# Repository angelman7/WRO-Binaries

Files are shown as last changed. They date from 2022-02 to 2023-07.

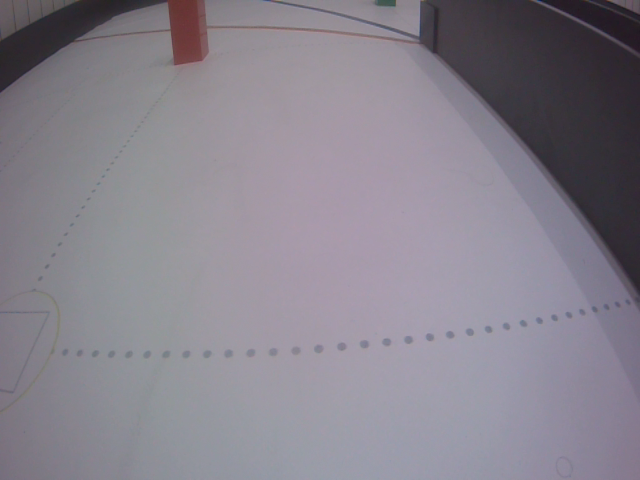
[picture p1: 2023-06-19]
jetson/scripts/images/img_12.png

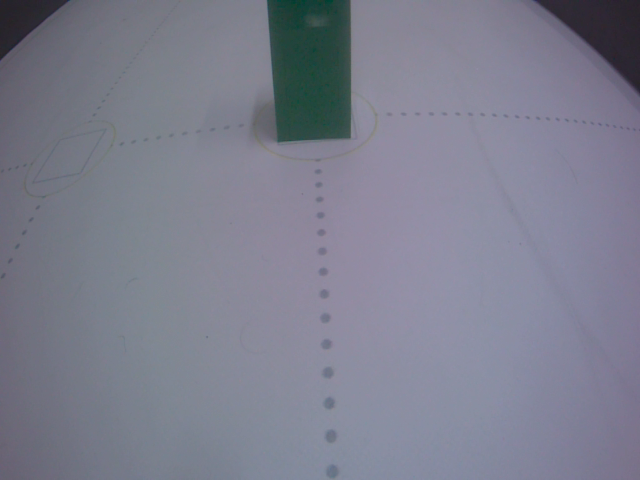
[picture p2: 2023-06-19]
jetson/scripts/images/img_3.png

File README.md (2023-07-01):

# WRO - Binaries

This repository contains engineering materials of a self-driven vehicle's model participating in the WRO Future Engineers competition in the season 2022 for the team Binaries.

## Content
* `t-photos` contains 2 photos of the team (an official one and one funny photo with all team members).
* `v-photos` contains 6 photos of the vehicle (from every side, from top and bottom).
* `video` contains the video.md file with the link to a video where driving demonstration exists.
* `schemes` contains one or several schematic diagrams in form of JPEG, PNG or PDF of the electromechanical components illustrating all the elements (electronic components and motors) used in the vehicle and how they connect to each other.
* `src` contains code of control software for all components which were programmed to participate in the competition.
* `models` is for the files for models used by 3D printers, laser cutting machines and CNC machines to produce the vehicle elements. If there is nothing to add to this location, the directory can be removed.
* `other` is for other files which can be used to understand how to prepare the vehicle for the competition. It may include documentation how to connect to a SBC/SBM and upload files there, datasets, hardware specifications, communication protocols descriptions etc. If there is nothing to add to this location, the directory can be removed.

## Introduction
First things first, the hardware consinsts of a Jetson Nano (running Linux) thats is the "mind" of the robot as it is where all the code is run.

Concerning the movement of the vehicle, a DC and a servo motor are used. The DC motor is responsible for the speed of the car while the servo motor is responsible for the steering of the car.

The Jetson Nano also utilises the power of R.O.S.(Robot Operating System) which is a set of software libraries and tools that let us build robot applications as this. From drivers to state-of-the-art algorithms, and with powerful developer tools.
Using R.O.S. all programs (besides the modules) can become a node and is able to publish and get information from other nodes through topics which is the perfect way for these programs to communicate.

The Jetson Nano also controls all the sensors used in our project:
* `1 color sensor` which detects the orange and blue line
* `2 laser distance sensors` that are used to determine the distance to the nearest wall from the fron oh the vehicle.
* `1 gyroscope / accelerometer` that is constantly use to determine and control the orientation of the vehicle.
* `1 camera` which is used to detect what is in front of the vehicle

On the software part the following programs and modules are used:
   - `pillar.py`
   - `run1.py` contains the main program that will run during the first part of the competition using the modules mentioned below.
   - `run2.py` contains the main program that will run during the second part of the competition using the modules mentioned below.
   - `modules`
       - `cnf.txt` contains many variables used by the car.py that were found through contious testing, like the color codes of the lines etc.
       - `bmm150.py`
       - `button.py` contains the class used to control the buttons that is used to detect whether or not a button is pressed.
       - `camera.py` contains the class used to read the camera.
       - `color.py` contains the class used for the color sensor and to check what it detects.
       - `compass.py` contains the class used to controll the compass and read the current orientation.
       - `cvtool.py` contains the class used to manage the camera and detect what and what type of obstacle is in front of the vehicle.
       - `drive.py` contains the class used for control and management of both the DC and servo.
       - `grove_i2c_bus.py` contains the bus used by the program grove_i2c_color_sensor_v2.py.
       - `grove_i2c_color_sesor_v2.py` contains the class used to control the I2C communication for both the OLED display and the Color Sensor.
       - `line2turn.py` contains the class used to detect and recognise the blue and orange lines on the field ground.
       - `oled.py` contains the class used to control the OLED display and showw text on it.
       - `oled_sample.py` a program used to debug the OLED display.
       - `wall.py` contains the class used by the camera to manage and detect and avoid any walls that might be in front of the vehicle correctly imminent.

**run1.py**
This program runs the program for the first challenge. It runs on a loop. Inside the loop, there is a hierarchy of activities that are performed for each frame of the camera. Firstly, the program checks, using the front distance sensors, whether or not the vehicle is dangerously close to a wall. Then, based on that information, a pid algorithm is used to calculate the steering angle of the vehicle. Then, the vehicle turns to avoid the wall. Alternatively, if no walls are detected it checks, through the distance sensor, whether or not the distance on the left or the right is over 2m, which signifies a left or right turn respectively. If any such distance is detected, left or right, the vehicle performes a 90 degree turn to move into the next section of the field. As the program uses an algorithm for the steering direction to stay parrallel to the walls, which is done using an angle target on the compass, a turn can be effectively executed by simply incrementing or dicrementing the target of the algorith by 90 degrees. After it has completed all the turns it stops in the starting sector. 

**run2.py** 
This program runs the program for the second challenge. It has multiple similarities to the run 1 function that runs in the first challenge. The only notable difference is that the program proceeds to check for pillars after the wall check. After the detection of a pillar, if it is present, the program will turn right or left, if needed, according to the distance, size and color (red or green) of the pillar. 

**pillar.py**
This file contains the program that has the finctionality of detecting the pillars and their position.

**cnf.txt**
The text file where values are stored after calibration, in order for them to be accessed and used by the run1 and run2 programs. 

**Modules Folder**
This is a folder that contains the modules that are used by the car.py program and by its numerous functions. 

# Credits - Libraries

- **Grove I2C Bus**

  **License**

  The MIT License (MIT)

  Grove Base Hat for the Raspberry Pi, used to connect grove sensors.
  Copyright (C) 2018  Seeed Technology Co.,Ltd. 

  Permission is hereby granted, free of charge, to any person obtaining a copy
  of this software and associated documentation files (the "Software"), to deal
  in the Software without restriction, including without limitation the rights
  to use, copy, modify, merge, publish, distribute, sublicense, and/or sell
  copies of the Software, and to permit persons to whom the Software is
  furnished to do so, subject to the following conditions:

  The above copyright notice and this permission notice shall be included in
  all copies or substantial portions of the Software.

  THE SOFTWARE IS PROVIDED "AS IS", WITHOUT WARRANTY OF ANY KIND, EXPRESS OR
  IMPLIED, INCLUDING BUT NOT LIMITED TO THE WARRANTIES OF MERCHANTABILITY,
  FITNESS FOR A PARTICULAR PURPOSE AND NONINFRINGEMENT. IN NO EVENT SHALL THE
  AUTHORS OR COPYRIGHT HOLDERS BE LIABLE FOR ANY CLAIM, DAMAGES OR OTHER
  LIABILITY, WHETHER IN AN ACTION OF CONTRACT, TORT OR OTHERWISE, ARISING FROM,
  OUT OF OR IN CONNECTION WITH THE SOFTWARE OR THE USE OR OTHER DEALINGS IN
  THE SOFTWARE.

 - **Grove I2C Color Sensor**
   
   Library for Grove - I2C Color Sensor V2(https://www.seeedstudio.com/Grove-I2C-Color-Sensor-V2-p-2890.html)

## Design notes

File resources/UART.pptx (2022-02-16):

## UART

Εφαρμογή με Jetson Nano & ESP32

## UART

- Το UART είναι η συντομογραφία του Universal Asynchronous Receiver/Transmitter.
- Είναι ένα κύκλωμα στους υπολογιστές το οποίο διαμεσολαβεί στην σειριακή επικοινωνία υπολογιστών ή υπολογιστών με συσκευές (ή και Embedded Computer Systems όπως μικροελεγκτές).
- Η ταχύτητα επικοινωνίας (ρυθμός μετάδοσης) μπορεί να παραμετροποιηθεί και μετριέται σε baud rate (bits/sec).
- Σήμερα το κύκλωμα UART είναι ενσωματωμένο ως κύκλωμα τσιπ μέσα στον υπολογιστή ή στην περιφερειακή συσκευή.

## UART

- Ένα UART παίρνει bytes δεδομένων και τα στέλνει σε σειριακή μορφή ως bits.
- Στον προορισμό ένα δεύτερο UART συλλέγει τα bits και δημιουργεί τα bytes δεδομένων που αποστάλθηκαν
- Η επικοινωνία μέσω του UART μπορεί να είναι απλή (simplex: προς μια κατεύθυνση μόνο - χωρίς να υπάρχει πρόβλεψη ο δέκτης να στείλει πίσω κάποιο σήμα), αμφίδρομη (πλήρης) ταυτόχρονη επικοινωνία (full duplex: και οι δύο συσκευές στέλνουν και δέχονται σήματα την ίδια στιγμή), αμφίδρομη εναλλασσόμενη επικοινωνία (half duplex: κάθε συσκευή παίρνει σειρά στο να αποστείλει ή να λάβει δεδομένα - δεν γίνεται αποστολή-λήψη την ίδια στιγμή)

## UART

- Κατά την επικοινωνία με UART στέλνονται πλαίσια δεδομένων (data frames) όπου το καθένα περιέχει ένα χαρακτήρα
- Το μέγεθος του πλαισίου χαρακτήρων μπορεί να είναι 10bits όπου υπάρχει ένα start bit και ένα stop bit στην αρχή και το τέλος και είναι διαθέσιμα 8 bits για την κωδικοποίηση του χαρακτήρα που στέλνουμε-παίρνουμε

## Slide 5

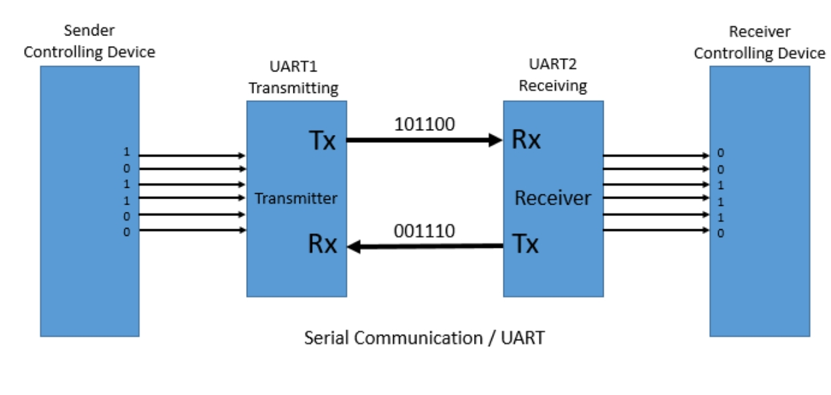
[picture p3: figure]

## Jetson Nano & ESP32

- Το Jetson Nano διαθέτει διάφορες θύρες UART, εμείς θα χρησιμοποιήσουμε τη θύρα που υποστηρίζεται από τα GPIOs D15 (RX) και D14 (TX), της οποία το όνομα είναι “/dev/ttyTHS1” (αυτό πρέπει αν το θυμόμαστε)
- Από την άλλη πλευρά θα έχουμε το ESP32, από το οποίο θα χρησιμοποιήσουμε τη θύρα που υποστηρίζεται από τα GIOPs 17 (ΤΧ2) και 16 (RX2), με όνομα τον αριθμό 2 (και αυτό πρέπει να το θυμόμαστε)
- Το TX του Jetson θα συνδεθεί με το RX του ESP32 και το RX του Jetson με το TX του ESP32

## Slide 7

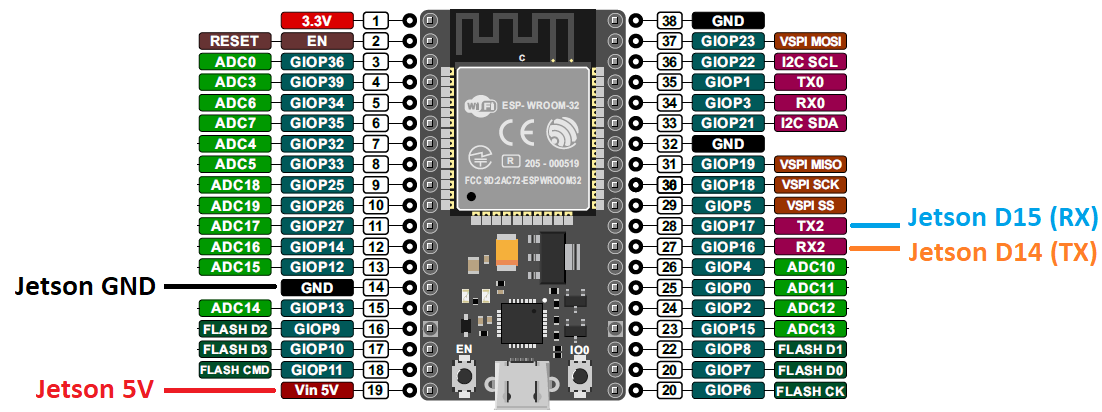
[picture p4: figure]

## MODULARITY

Jetson Nano
- Αξιοποίηση κάμερας ως αισθητήρα
- Ανίχνευση αντικειμένων ενδιαφέροντος
  - CV
  - Deep Learning
- Αποστολή δεδομένων στο UART

## MODULARITY

ESP32
- Διάβασμα αισθητήρων
  - Color, buttons, compass, gyroscope, accelerator …
- Λήψη δεδομένων από UART
- Επεξεργασία δεδομένων – μετρήσεων
  - PID controllers etc
- Έλεγχος actuators
  - DC Κινητήρας, steering κινητήρας, OLED, LEDs, buzzers …

## Jetson & ESP32

- Ο διαχωρισμός των λειτουργιών που θα υποστηρίζει ο κάθε ελεγκτής θα πρέπει να είναι σαφής και να μην επηρεάζεται η μεταξύ τους λειτουργία
- Απαραίτητος ο απομακρυσμένος έλεγχος του συστήματος:
  - Παρακολούθηση και διαχείριση του Jetson χωρίς την απευθείας σύνδεσή του με περιφερειακά (πληκτρολόγιο, οθόνη κλπ)
  - Παρακολούθηση των λήψεων της κάμερας για σκοπούς debugging
  - Δυνατότητα ελέγχου των κινητήρων και παρακολούθησης των αισθητήρων του ESP32 από τον χρήστη
  - Αυτοματοποίηση/τυποποίηση της διαδικασία “εκπαίδευσης”
    - Διαμόρφωση των thresholds στα επιθυμητά color spaces
    - Transfer learning σε DNN μοντέλα
    - …

## ESP32 – Micropython

from machine import UART
from time import time, sleep
from random import randrange
uart = UART(2, 115200)
kick = time()
while True:
if time() - kick > 1:
num = str(randrange(-10, 11))
uart.write(num.encode())
kick = time()
if uart.any():
message = uart.read().decode()
print(message)

## Jetson - Python

- https://github.com/JetsonHacksNano/UARTDemo

git clone https://github.com/JetsonHacksNano/UARTDemo
cd UARTDemo
sudo chmod 666 /dev/ttyTHS1
sudo python3 uart_example.py

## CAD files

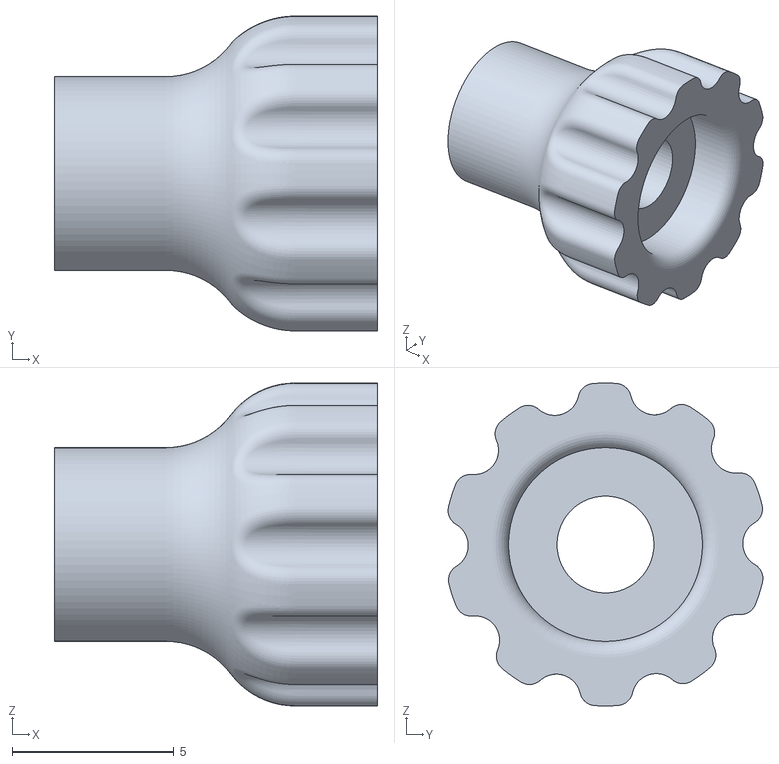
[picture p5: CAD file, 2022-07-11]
models/Camera_Rpi_Handle.stl
10.0 x 9.75 x 10.00

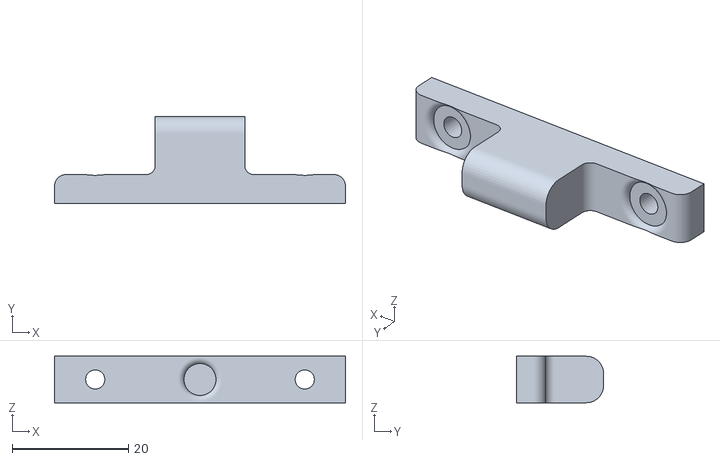
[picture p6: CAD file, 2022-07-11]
models/Camera_Rpi_Base.stl
50.0 x 15.0 x 8.00

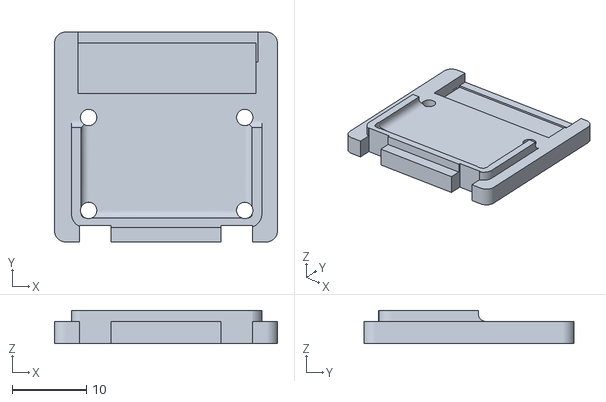
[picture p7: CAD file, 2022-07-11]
models/Camera_Rpi_Back.stl
30.0 x 28.2 x 4.50

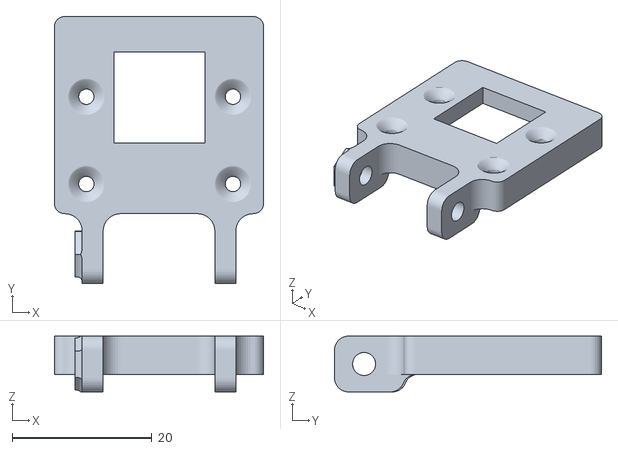
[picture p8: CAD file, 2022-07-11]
models/Camera_Rpi_Front.stl
30.0 x 38.2 x 8.00

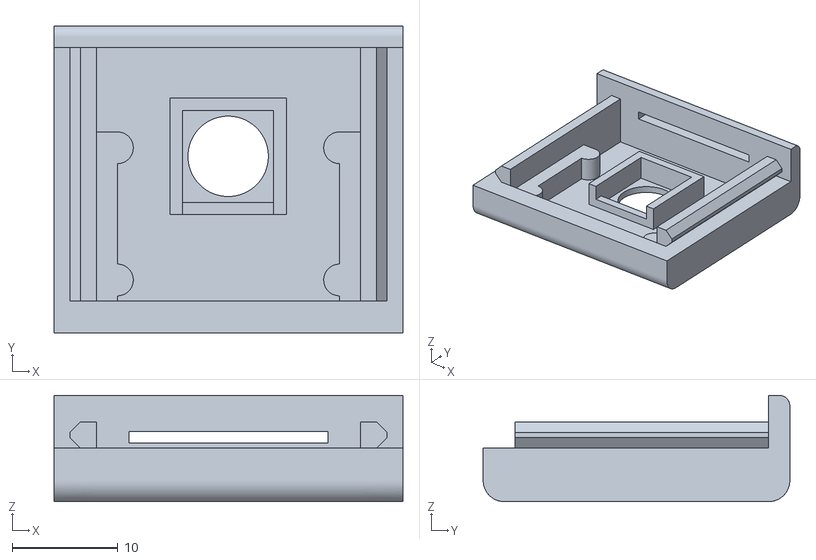
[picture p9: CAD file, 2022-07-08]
models/Cam-Housing-Front.stl
33.0 x 29.0 x 10.1

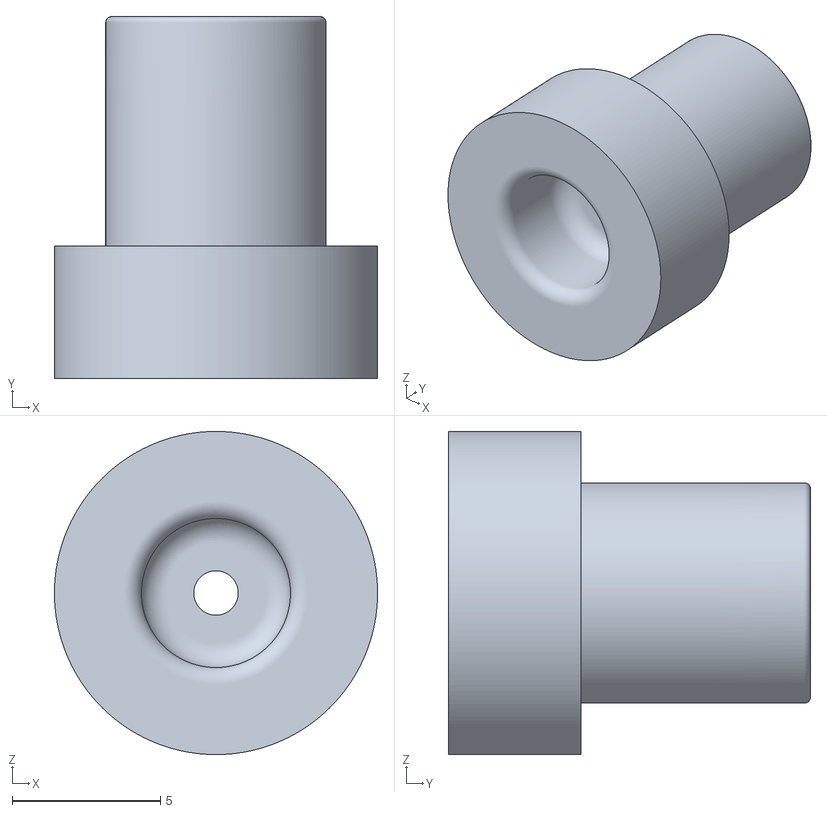
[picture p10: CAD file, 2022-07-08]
models/Servo-Connector.stl
10.9 x 12.2 x 10.9

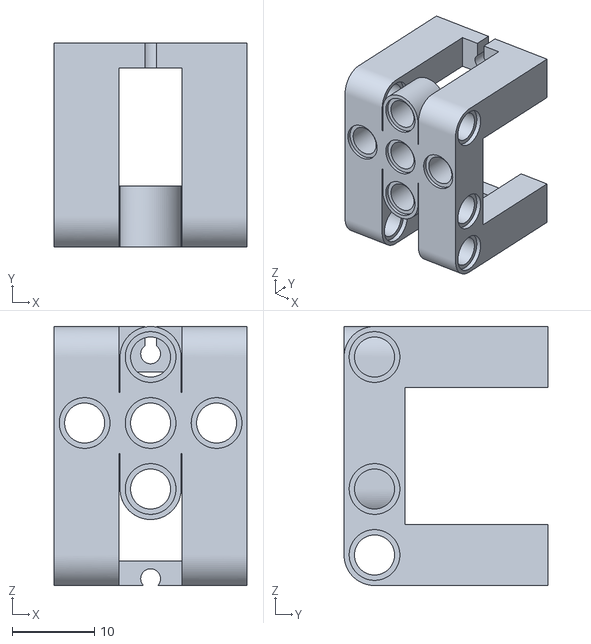
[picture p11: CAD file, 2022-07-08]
models/Servo-Bottom-holder.stl
23.4 x 24.7 x 31.4

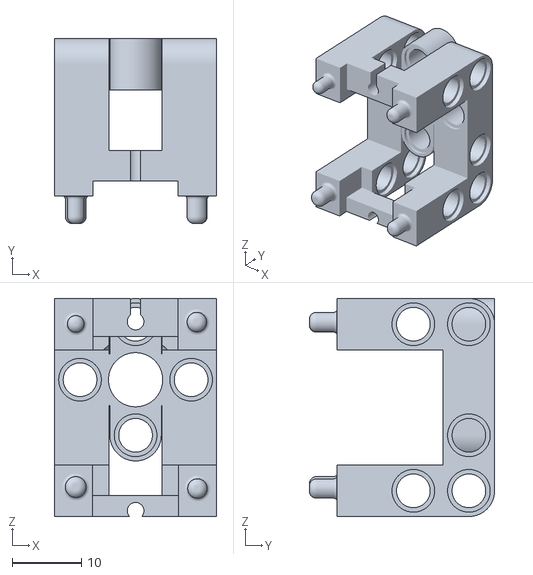
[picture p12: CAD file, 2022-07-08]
models/Servo-Top-holder.stl
23.4 x 26.7 x 31.4

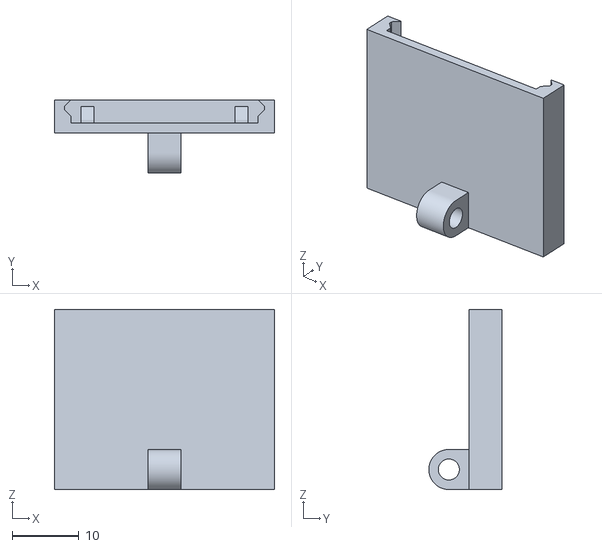
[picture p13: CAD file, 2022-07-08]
models/Cam-Housing-Back.stl
33.0 x 11.0 x 27.0

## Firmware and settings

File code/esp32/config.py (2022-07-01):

'''
MAIN CONFIGURATION FILE
'''
from machine import I2C, Pin, ADC, PWM # to manage ESP32
import ssd1306 # to manage OLED display
from time import sleep, time # to manage time
from math import pi, atan2, floor 
from ustruct import pack # to write data in sensors' registers
from array import array # to read bytes from sensors' registers
from json import loads# to read files
from hcsr04 import HCSR04

# I2C Color Sensor registers and commands
_CMD_CS      = 0x80
_AUTO_CS     = 0x20

_ENABLE_CS   = 0x00
_ATIME_CS    = 0x01
_WTIME_CS    = 0x03
_AILT_CS     = 0x04
_AIHT_CS     = 0x06
_PERS_CS     = 0x0C
_CONFIG_CS   = 0x0D
_CONTROL_CS  = 0x0F
_ID_CS       = 0x12
_STATUS_CS   = 0x13
_CDATA_CS    = 0x14
_RDATA_CS    = 0x16
_GDATA_CS    = 0x18
_BDATA_CS    = 0x1A

_AIEN_CS       = 0x10
_WEN_CS        = 0x08
_AEN_CS        = 0x02
_PON_CS        = 0x01

_GAINS_CS  = (1, 4, 16, 60)

PIN_SCL = 22
PIN_SDA = 21
PIN_POT = 36
PIN_NEXT_BTN = 2
PIN_PREV_BTN = 5
PIN_HIT_BTN = 0
PIN_IN1 = 12
PIN_IN2 = 14
PIN_ENA = 27
PIN_SERVO = 26
PIN_TRIG_LEFT = 33
PIN_ECHO_LEFT = 32
PIN_TRIG_RIGHT = 19
PIN_ECHO_RIGHT = 18

def map(x, in_min, in_max, out_min, out_max):
    return int(out_min + x *(out_max - out_min)/(in_max - in_min))

class Distance:
    def __init__(self):
        self.left_sensor = HCSR04(trigger_pin=PIN_TRIG_LEFT, echo_pin=PIN_ECHO_LEFT)
        self.right_sensor = HCSR04(trigger_pin=PIN_TRIG_RIGHT, echo_pin=PIN_ECHO_RIGHT)

    def right(self):
        return self.right_sensor.distance_cm()

    def left(self):
        return self.left_sensor.distance_cm()
        
class Display:
    def __init__(self):
        i2c = I2C(1, scl=Pin(PIN_SCL), sda=Pin(PIN_SDA))
        oled_width = 128
        oled_height = 64
        self.oled = ssd1306.SSD1306_I2C(oled_width, oled_height, i2c)
        
    def show_text_list(self, text_list, selected=-1):
        
        self.oled.fill(0)
        for i, t in enumerate(text_list):
            if selected == i:
                self.oled.text('>' + t, 0, i * 10)
            else:
                self.oled.text(t, 0, i * 10)
        self.oled.show()
        
    def show_text(self, text):
        self.oled.fill(0)
        self.oled.text(text, 0, 0)
        self.oled.show()

    def show_big_text(self, big_text):
        line = ""
        lines = []
        for c in big_text:
            if len(line) < 16:
                line += c
            else:
                lines.append(line)
                line = ""
                line += c
        if line != "":
            lines.append(line)
        print(lines)
        self.show_text_list(lines)
        
class Buttons:
    def __init__(self):
        self.next_button = Pin(PIN_NEXT_BTN, Pin.IN, Pin.PULL_UP) # DOWN
        self.hit_button = Pin(PIN_HIT_BTN, Pin.IN, Pin.PULL_UP) # CENTER
        self.previous_button = Pin(PIN_PREV_BTN, Pin.IN, Pin.PULL_UP) # UP
        
    def next_is_pressed(self):
        return True if self.next_button.value() == 0 else False
    
    def hit_is_pressed(self):
        return True if self.hit_button.value() == 0 else False
    
    def previous_is_pressed(self):
        return True if self.previous_button.value() == 0 else False

    def any_is_pressed(self):
        return self.next_button.value() == 0 or self.hit_button.value() == 0 or self.previous_button.value() == 0
    
    def wait_next(self):
        while self.next_button.value() == 1:
            pass
            
    def wait_hit(self):
        while self.hit_button.value() == 1:
            pass
        
    def wait_previous(self):
        while self.previous_button.value() == 1:
            pass

    def wait_button(self, buttons=["HIT", "NEXT", "PREVIOUS"]):
        while True:
            if self.hit_is_pressed() and "HIT" in buttons:
                return "HIT"
            if self.next_is_pressed() and "NEXT" in buttons:
                return "NEXT"
            if self.previous_is_pressed() and "PREVIOUS" in buttons:
                return "PREVIOUS"
        
class Compass:
    __gain__ = {
        '0.88': (0 << 5, 0.73),
        '1.3':  (1 << 5, 0.92),
        '1.9':  (2 << 5, 1.22),
        '2.5':  (3 << 5, 1.52),
        '4.0':  (4 << 5, 2.27),
        '4.7':  (5 << 5, 2.56),
        '5.6':  (6 << 5, 3.03),
        '8.1':  (7 << 5, 4.35)
    }

    # Correction to be set after calibration
    xs=1
    ys=1
    xb=0
    yb=0

    def __init__(self, scl=22, sda=21, address=0x1e, gauss='1.9', declination=(4, 54), 
                    cnf_file="cnf.txt"):
        self.orientation = {'forward':0, "backward":0, "left":0, "right":0}
        self.correction_values = {"xs":1, "ys":1, "xb":0, "yb":0}
        self.i2c = i2c = I2C(1, scl=Pin(22), sda=Pin(21))
        self.address = address
        
        i2c.writeto_mem(self.address, 0x00, pack('B', 0b111000))

        reg_value, self.gain = self.__gain__[gauss]
        i2c.writeto_mem(self.address, 0x01, pack('B', reg_value))

        i2c.writeto_mem(self.address, 0x02, pack('B', 0x00))
        self.declination = (declination[0] + declination[1] / 60) * pi / 180

        self.data = array('B', [0] * 6)
        self.cnf_file = cnf_file

        self.read_cnf_file()
        self.current_orientation = "forward"

    def init_orientation(self):
        degrees = self.read_degrees()
        for ort in self.orientation:
            min_value = (359 + self.orientation[ort] - 10) % 360
            max_value = (self.orientation[ort] + 10) % 360
            if min_value > max_value:
                min_value, max_value = max_value, min_value
            if min_value < degrees < max_value:
                if ort == "right":
                    self.orientation["forward"], self.orientation["left"], self.orientation["back"], self.orientation["right"] = self.orientation["right"], self.orientation["back"], self.orientation["left"], self.orientation["forward"] 
                elif ort == "back":
                    self.orientation["forward"], self.orientation["left"], self.orientation["back"], self.orientation["right"] = self.orientation["back"], self.orientation["left"], self.orientation["forward"], self.orientation["right"] 
                elif ort == "left":
                    self.orientation["forward"], self.orientation["left"], self.orientation["back"], self.orientation["right"] = self.orientation["left"], self.orientation["forward"], self.orientation["right"], self.orientation["back"] 
            break

    def read(self):
        data = self.data
        gain = self.gain

        self.i2c.readfrom_mem_into(self.address, 0x03, data)
        
        x = (data[0] << 8) | data[1]
        z = (data[2] << 8) | data[3]
        y = (data[4] << 8) | data[5]

        x = x - (1 << 16) if x & (1 << 15) else x
        y = y - (1 << 16) if y & (1 << 15) else y
        z = z - (1 << 16) if z & (1 << 15) else z

        x = x * gain
        y = y * gain
        z = z * gain
        
        # Apply calibration corrections
        x = x * self.xs + self.xb
        y = y * self.ys + self.yb

        return x, y, z

    def heading(self, x, y):
        heading_rad = atan2(y, x)
        heading_rad += self.declination

        # Correct reverse heading.
        if heading_rad < 0:
            heading_rad += 2 * pi

        # Compensate for wrapping.
        elif heading_rad > 2 * pi:
            heading_rad -= 2 * pi

        # Convert from radians to degrees.
        heading = heading_rad * 180 / pi
        degrees = floor(heading)
        minutes = round((heading - degrees) * 60)
        return degrees, minutes

    def read_degrees(self):
        x, y, z = self.read()
        return self.heading(x, y)[0]

    def format_result(self, x, y, z):
        degrees, minutes = self.heading(x, y)
        return 'X: {:.4f}, Y: {:.4f}, Z: {:.4f}, Heading: {}° {} '.format(x, y, z, degrees, minutes)

    def read_cnf_file(self):
        self.orientation = {'forward':0, "backward":0, "left":0, "right":0}
        self.correction_values = {"xs":1, "ys":1, "xb":0, "yb":0}
        with open(self.cnf_file, 'a') as f:
            for line in f:
                #print(line)
                dict_line = loads(line)
                if dict_line["data"] == "compass":
                    self.orientation['forward'] = dict_line["forward"]
                    self.orientation['backward'] = dict_line["backward"]
                    self.orientation['left'] = dict_line["left"]
                    self.orientation['right'] = dict_line["right"]
                    self.correction_values['xs'] = dict_line["xs"]
                    self.correction_values['ys'] = dict_line["ys"]
                    self.correction_values['xb'] = dict_line["xb"]
                    self.correction_values['yb'] = dict_line["yb"]
                    break
                
    def write_cnf_file(self, orientation=None, corrections=None):
        replacement = ""
        # read file to change the values
        with open(self.cnf_file, 'r') as f:
            # using the for loop
            for line in f:
                dict_line = loads(line)
                if dict_line["data"] == "compass":
                    if orientation is not None:
                        dict_line["forward"] = orientation["forward"]
                        dict_line["backward"] = orientation["backward"]
                        dict_line["left"] = orientation["left"]
                        dict_line["right"] = orientation["right"]
                    if corrections is not None:
                        dict_line["xs"] = corrections['xs']
                        dict_line["ys"] = corrections['ys']
                        dict_line["xb"] = corrections['xb']
                        dict_line["yb"] = corrections['yb']
                replacement = replacement + str(dict_line) + "\n"
        sleep(0.1)
        # re-write the file with the new values
        with open(self.cnf_file, 'w') as f:
            f.write(replacement.replace("\'", "\""))

class ColorSensor:
    """Driver for Grove I2C Color Sensor (TCS34725)"""

    def __init__(self, address=0x29, scl=22, sda=21, cnf_file="cnf.txt"):
        self.hsv_lines = None
        self.cnf_file = cnf_file
        self.i2c = I2C(1, scl=Pin(scl), sda=Pin(sda))
        
        self.address = address

        self.awake = False

        self.set_integration_time(24)
        self.set_gain(4)

        # read configuration file to update color ranges of lines
        self.read_cnf_file()

    def detect_color(self):
        # self.hsv_lines = {'white_min':0, "white_max":0, 'orange_min':0, "orange_max":0, "blue_min":0, "blue_max":0}
        hsv_values = self.hsv()
        if self.hsv_lines["white_hmin"] <= hsv_values[0] <= self.hsv_lines["white_hmax"] and \
            self.hsv_lines["white_vmin"] <= hsv_values[2] <= self.hsv_lines["white_vmax"]:
                #self.hsv_lines["white_smin"] <= hsv_values[1] <= self.hsv_lines["white_smax"] and \
                
            return "white"
        if self.hsv_lines["orange_hmin"] <= hsv_values[0] <= self.hsv_lines["orange_hmax"] and \
            self.hsv_lines["orange_vmin"] <= hsv_values[2] <= self.hsv_lines["orange_vmax"]:
                #self.hsv_lines["orange_smin"] <= hsv_values[1] <= self.hsv_lines["orange_smax"] and \
            return "orange"
        if self.hsv_lines["blue_hmin"] <= hsv_values[0] <= self.hsv_lines["blue_hmax"] and \
            self.hsv_lines["blue_vmin"] <= hsv_values[2] <= self.hsv_lines["blue_vmax"]:
                #self.hsv_lines["blue_smin"] <= hsv_values[1] <= self.hsv_lines["blue_smax"] and \
                
            return "blue"
        return "uknown"
        
    def line_calibration_is_valid(self, new_hsv_lines):
        if new_hsv_lines == None:
            return False
        for i in range(0, 360):
            if i in range(new_hsv_lines['white_hmin'], new_hsv_lines['white_hmax'] + 1) and \
                i in range(new_hsv_lines['orange_hmin'], new_hsv_lines['orange_hmax'] + 1) and \
                    i in range(new_hsv_lines['blue_hmin'], new_hsv_lines['blue_hmax'] + 1):
                    return False
        return True

    def wakeup(self):
        enable = self._read_byte(_ENABLE_CS)
        self._write_byte(_ENABLE_CS, enable | _PON_CS | _AEN_CS)
        sleep(0.0024)

        self.awake = True

    def sleep(self):
        enable = self._read_byte(_ENABLE_CS)
        self._write_byte(_ENABLE_CS, enable & ~_PON_CS)

        self.awake = False

    def is_awake(self):
        return self._read_byte(_ENABLE_CS) & _PON_CS

    def set_wait_time(self, t):
        pass

    def id(self):
        return self._read_byte(_ID_CS)

    def integration_time(self):
        steps = 256 - self._read_byte(_ATIME_CS)
        return steps * 2.4

    def set_integration_time(self, t):
        """Set the integration time of the sensor"""
        if t < 2.4:
            t = 2.4
        elif t > 614.4:
            t = 614.4
        
        steps = int(t / 2.4)
        self._integration_time = steps * 2.4
        self._write_byte(_ATIME_CS, 256 - steps)

    def gain(self):
        """The gain control. Should be 1, 4, 16, or 60.
        """
        return _GAINS_CS[self._read_byte(_CONTROL_CS)]

    def set_gain(self, gain):
        if gain in _GAINS_CS:
            self._write_byte(_CONTROL_CS, _GAINS_CS.index(gain))

    def raw(self):
        """Read RGBC registers
        return 16 bits red, green, blue and clear data
        """

        if not self.awake:
            self.wakeup()

        while not self._valid():
            sleep(0.0024)

        data = tuple(self._read_word(reg) for reg in (_RDATA_CS, _GDATA_CS, _BDATA_CS, _CDATA_CS))
        return data

    def hsv(self):
        r, g, b, clear = self.raw()
        
        if clear:
            r = r / clear
            g = g / clear
            b = b / clear
        else:
            r, g, b = 0, 0, 0

        #r, g, b = r / 255, g / 255, b / 255
        maxc = max(r, g, b)
        minc = min(r, g, b)
        v = maxc
        if minc == maxc:
            return 0.0, 0.0, v
        s = (maxc-minc) / maxc
        rc = (maxc-r) / (maxc-minc)
        gc = (maxc-g) / (maxc-minc)
        bc = (maxc-b) / (maxc-minc)
        if r == maxc:
            h = bc-gc
        elif g == maxc:
            h = 2.0+rc-bc
        else:
            h = 4.0+gc-rc
        h = (h/6.0) % 1.0
        return min(359, int(h*359)), min(255, int(s*255)), min(255, int(v*255))
        
    def rgb(self):
        """Read the RGB color detected by the sensor.  Returns a 3-tuple of
        red, green, blue component values as bytes (0-255).
        """
        r, g, b, clear = self.raw()
        
        if clear:
            r = int(255 * r / clear)
            g = int(255 * g / clear)
            b = int(255 * b / clear)
        else:
            r, g, b = 0, 0, 0
        return r, g, b

    def _valid(self):
        """Check if RGBC is valid"""
        return self._read_byte(_STATUS_CS) & 0x01

    def _read_byte(self, address):
    
        command = _CMD_CS | address
        data = array('B', [0])
        self.i2c.readfrom_mem_into(self.address, command, data)
        return data[0]

    def _read_word(self, address):
        command = _CMD_CS | _AUTO_CS | address
        data = array('B', [0] * 2)
        self.i2c.readfrom_mem_into(self.address, command, data)#self.bus.read_word_data(self.address, command)
        
        return (data[0] << 8) | data[1]

    def _write_byte(self, address, data):
        command = _CMD_CS | address
        self.i2c.writeto_mem(self.address, command, pack('B', data)) # pack('B', 0b111000)
        #self.bus.write_byte_data(self.address, command, data)

    def _write_word(self, address, data):
        command = _CMD_CS | _AUTO_CS | address
        data = [(data >> 8) & 0xFF, data & 0xFF]
        self.i2c.writeto_mem(self.address, command, pack('B', data))
        #self.bus.write_i2c_block_data(self.address, command, data)

    def read_cnf_file(self):
        self.hsv_lines = {"white_hmin":0, "white_hmax":0, "white_smin":0, "white_smax":0, "white_vmin":0, 
                        "white_vmax":0, "orange_hmin":0, "orange_hmax":0, "orange_smin":0, "orange_smax":0, 
                        "orange_vmin":0, "orange_vmax":0, "blue_hmin":0, "blue_hmax":0, "blue_smin":0, 
                        "blue_smax":0, "blue_vmin":0, "blue_vmax":0}
        with open(self.cnf_file, 'a') as f:
            for line in f:
                #print(line)
                dict_line = loads(line)
                if dict_line["data"] == "hsv_lines":
                    self.hsv_lines['white_hmin'] = dict_line["white_hmin"]
                    self.hsv_lines['white_hmax'] = dict_line["white_hmax"]
                    self.hsv_lines['white_smin'] = dict_line["white_smin"]
                    self.hsv_lines['white_smax'] = dict_line["white_smax"]
                    self.hsv_lines['white_vmin'] = dict_line["white_vmin"]
                    self.hsv_lines['white_vmax'] = dict_line["white_vmax"]
                    self.hsv_lines['orange_hmin'] = dict_line["orange_hmin"]
                    self.hsv_lines['orange_hmax'] = dict_line["orange_hmax"]
                    self.hsv_lines['orange_smin'] = dict_line["orange_smin"]
                    self.hsv_lines['orange_smax'] = dict_line["orange_smax"]
                    self.hsv_lines['orange_vmin'] = dict_line["orange_vmin"]
                    self.hsv_lines['orange_vmax'] = dict_line["orange_vmax"]
                    self.hsv_lines['blue_hmin'] = dict_line["blue_hmin"]
                    self.hsv_lines['blue_hmax'] = dict_line["blue_hmax"]
                    self.hsv_lines['blue_smin'] = dict_line["blue_smin"]
                    self.hsv_lines['blue_smax'] = dict_line["blue_smax"]
                    self.hsv_lines['blue_vmin'] = dict_line["blue_vmin"]
                    self.hsv_lines['blue_vmax'] = dict_line["blue_vmax"]
                    break
                
    def write_cnf_file(self, hsv_lines):
        replacement = ""
        # read file to change the values
        with open(self.cnf_file, 'r') as f:
            # using the for loop
            for line in f:
                dict_line = loads(line)
                if dict_line["data"] == "hsv_lines":
                    dict_line["white_hmin"] = hsv_lines["white_hmin"]
                    dict_line["white_hmax"] = hsv_lines["white_hmax"]
                    dict_line["white_smin"] = hsv_lines["white_smin"]
                    dict_line["white_smax"] = hsv_lines["white_smax"]
                    dict_line["white_vmin"] = hsv_lines["white_vmin"]
                    dict_line["white_vmax"] = hsv_lines["white_vmax"]
                    
                    dict_line["orange_hmin"] = hsv_lines["orange_hmin"]
                    dict_line["orange_hmax"] = hsv_lines["orange_hmax"]
                    dict_line["orange_smin"] = hsv_lines["orange_smin"]
                    dict_line["orange_smax"] = hsv_lines["orange_smax"]
                    dict_line["orange_vmin"] = hsv_lines["orange_vmin"]
                    dict_line["orange_vmax"] = hsv_lines["orange_vmax"]
                    
                    dict_line["blue_hmin"] = hsv_lines["blue_hmin"]
                    dict_line["blue_hmax"] = hsv_lines["blue_hmax"]
                    dict_line["blue_smin"] = hsv_lines["blue_smin"]
                    dict_line["blue_smax"] = hsv_lines["blue_smax"]
                    dict_line["blue_vmin"] = hsv_lines["blue_vmin"]
                    dict_line["blue_vmax"] = hsv_lines["blue_vmax"]
                replacement = replacement + str(dict_line) + "\n"
        sleep(0.1)
        # re-write the file with the new values
        with open(self.cnf_file, 'w') as f:
            f.write(replacement.replace("\'", "\""))

class DC:
    def __init__(self):
        self.in1 = Pin(PIN_IN1, Pin.OUT)
        self.in1.value(0)
        self.in2 = Pin(PIN_IN2, Pin.OUT)
        self.in2.value(0)
        self.ena = PWM(Pin(PIN_ENA), freq=50, duty=0)
        self.pot = ADC(Pin(PIN_POT))
        self.pot.atten(ADC.ATTN_11DB)
        self.pot.width(ADC.WIDTH_10BIT)
        self.max_pwm = 1023
        self.forward = True

    def set_direction(self, forward=True):
        if forward:
            self.forward = True
            self.in1.value(0)
            self.in2.value(1)
        else:
            self.forward = False
            self.in1.value(1)
            self.in2.value(0)

    def stop(self):
        self.in1.value(0)
        self.in2.value(0)

    def update_max_speed(self):
        self.max_pwm = self.pot.read()

    def read_pot(self):
        return self.pot.read()

    def move(self, speed=50, forward=True):
        speed_duty = int((self.max_pwm * speed) / 100)
        self.ena.duty(speed_duty)
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

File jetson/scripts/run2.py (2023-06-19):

#!/usr/bin/env python3
import rospy, time
from std_msgs.msg import String, Int16, Int16MultiArray, Int32MultiArray, Int8
import steering
from modules.pid import PID
from modules.button import Button
import RPi.GPIO as GPIO

encoder = Int32MultiArray() # left_encoder, main_encoder, right_encoder
encoder.data = [0, 0, 0]
# pillar_array.data = ["color", "cx", "cy", "height", "center"]
pillar = Int16MultiArray()
pillar.data = [0, 0, 0, 0, 0]
left_distance = right_distance = 0
gyro_pos = 0
line = 0
state = 0
steer = steering.Steering()
reference_angle = 0
gyro_target = 0
pub = rospy.Publisher('speed', String, queue_size=10)


def change_state(channel):
    global state

    if state == 0:
        state = 1
        rospy.loginfo("State changed to 1")
    elif state == 1:
        state = -1
        rospy.loginfo("State changed to -1")
    

button = Button(pin=21, method_to_run=change_state)

def line_callback(data):
    global line

    # rospy.loginfo(rospy.get_caller_id() + "Line %s", data.data)
    line = data.data

def reset_gyro_angle():
    global reference_angle

    reference_angle = gyro_pos

def read_angle():
    return reference_angle - gyro_pos


def distance_callback(data):
    global left_distance, right_distance

    #rospy.loginfo(rospy.get_caller_id() + "Distances %s", data.data)
    left_distance = data.data[0]
    right_distance = data.data[1]
    # print("LD: ", left_distance)
    # print("RD: ", right_distance)


def gyro_callback(data):
    global gyro_pos

    #rospy.loginfo(rospy.get_caller_id() + "Gyro angle %s", str(data.data))
    gyro_pos = data.data


def encoders_callback(data):
    global encoder

    #rospy.loginfo(rospy.get_caller_id() + "Encoders %s", data.data)
    encoder = data
    # print("Encoder: ", encoder.data)

def pillar_callback(data):
    global pillar

    # rospy.loginfo(rospy.get_caller_id() + "Pillar %s", data.data)
    pillar = data
    # print("Pillar: ", pillar.data)

    
def dc_speed(speed=0):
    msg = str(speed)
    #rospy.loginfo(msg)
    pub.publish(msg)


def get_target(color, center, height, kc=1, kh=1, min_center=30):
        center = (100 + center)/2
        # print("Color:", color)
        # print("Center:", center)
        if color == 1 and center > min_center:
            t = kc * center + (kh * 100 * height)/300
            # print("t:", t)
            return min(max(-100, int(t)), 100)
        if color == -1 and center < 100 - min_center:
            t = kc * center + (kh * 100 * height)/300
            # print("t:", t)
            return -1 * min(max(-100, int(t)), 100)
        #     return -1 * min(max(-100, int(kc * (100 + center)/2 + (kh * 100 * height)/300)), 100)
        return None


def drive_gyro(speed=50, main_position=0, pid_ks=(1, 0, 0)):
    global line, current_path, previous_path, gyro_target

    # Initialise PID object
    pid = PID(pid_ks[0], pid_ks[1], pid_ks[2])
    pid.SetPoint = 0
    pid.setSampleTime(0.005)
    dc_speed(speed)
    print("RUNNING")
    
    turns = 0
    last_pillar_turn_ticks = 0
    pillar_ticks_delay = 600

    last_wall_turn_ticks = 0
    wall_ticks_delay = 350

    min_wall_distance = 80
    
    current_path = 0
    previous_path = -1
    turns = 0
    gyro_target = main_position
    direction = 0
    last_turn_ticks = 0
    turn_ticks = 9000
    while state == 1 and not rospy.is_shutdown() and turns < 666:
        # Check line to change gyro target
        error = read_angle() + gyro_target
        
        turn_left_distance = left_distance > 1000 and abs(error) < 20
        turn_right_distance = right_distance > 1000 and abs(error) < 20
        
        if turn_left_distance:
            direction = -1
        elif turn_right_distance:
            direction = 1
        if line != 0: # and ticks - last_line_turn_ticks > line_ticks_delay: #current_ms - last_line_turn_ms > line_delay:
            if encoder.data[1] - last_turn_ticks > turn_ticks:
                direction = line
            else:
                line = 0

        if encoder.data[1] - last_turn_ticks > turn_ticks and direction != 0:
            last_turn_ticks = encoder.data[1]
            gyro_target += -1*direction*90
            line = 0
            turns += 1
            rospy.loginfo("Turn " + str(turns) + ": " + str(direction) + ", ticks:" + str(encoder.data[1]))
        elif direction != 0:
            direction = 0
                    
        # 1st priority the wall
        if left_distance < min_wall_distance:
            rospy.loginfo("L-Wall fix")
            # rospy.loginfo("left wall " + str(left_distance))
            steer.set_steering(100)
            last_wall_turn_ticks = encoder.data[1]
            
        if right_distance < min_wall_distance:
            rospy.loginfo("R-Wall fix")
            # rospy.loginfo("right wall " + str(right_distance))
            steer.set_steering(-100)
            last_wall_turn_ticks = encoder.data[1]
            
        # 2nd priority the pillar
        # rospy.loginfo("pillar_cont")
        if encoder.data[1] - last_wall_turn_ticks > wall_ticks_delay:
            target = get_target(pillar.data[0], pillar.data[4], pillar.data[3], kc=0.6, kh=0.6, min_center=5)                
            if target is not None:
                rospy.loginfo("Pillar fix")
                # rospy.loginfo("pillar:" + str(target))
                steer.set_steering(target)
                last_pillar_turn_ticks = encoder.data[1]                
        if encoder.data[1] - last_pillar_turn_ticks > pillar_ticks_delay and encoder.data[1] - last_wall_turn_ticks > wall_ticks_delay:
            rospy.loginfo("Gyro fix")
            # Calculate error
            error = read_angle() + gyro_target
            # Calculate the correction value with the PID object
            pid.update(error)
            u = int(pid.output)
            current_steer = int(min(100, max(u, -100)))
            steer.set_steering(current_steer)
    rospy.loginfo("Ticks: " + str(encoder.data[1]))
    dc_speed(0)
    steer.set_steering(0)




def listener():
    rospy.init_node('run2', anonymous=False)

    rospy.Subscriber("line", Int8, line_callback)
    rospy.Subscriber("lrdistance", Int16MultiArray, distance_callback)
    rospy.Subscriber("gyro_angle", Int16, gyro_callback)
    rospy.Subscriber("pillar_topic", Int16MultiArray, pillar_callback)
    rospy.Subscriber("encoders", Int32MultiArray, encoders_callback)

    rate = rospy.Rate(100) 
    dc_speed(0)
    steer.set_steering(0)
    time.sleep(2)

    rospy.loginfo("Wait to push button")
    while state == 0:
        pass
    
    # while not rospy.is_shutdown():
    #     target = get_target(pillar.data[0], pillar.data[4], pillar.data[3], kc=0.6, kh=0.6, min_center=5)
    #     rospy.loginfo(str(target))
    #     rate.sleep()
    
    reset_gyro_angle()
    drive_gyro(speed=35, main_position=0, pid_ks=(1.5, 0.01, 0.002))
    
    
    GPIO.cleanup()

if __name__ == '__main__':
    listener()

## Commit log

2022-02-12 jetson pillar_detection.py -> PillarDetector.detect_pillars
2022-02-12 esp32 serial_communication
2022-02-12 jetson pillar_detection.py
2022-02-12 jetson folder reorder
2022-02-12 jetson programs
2022-02-13 jetson logging
2022-02-13 jetson general cleanup
2022-02-13 esp32 serial communication class rename
2022-02-13 jetson logging update
2022-02-16 error codes & deletion of the main sample code
    [run1.py, run2.py]
2022-02-19 esp32 and motors/sensors communication
2022-02-25 Preparations- συνδεσμολογίες, modules αισθήρων, κλπ
2022-03-02 servo angles, oled supoort added
2022-03-02 Preparations- συνδεσμολογίες, modules αισθητήρων, κλπ
2022-03-02 servo control - done in class
2022-03-05 added basic metal servo commands for future use
2022-05-28 Update esp32 main.py
